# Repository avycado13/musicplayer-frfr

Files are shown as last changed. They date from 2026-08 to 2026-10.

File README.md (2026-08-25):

# Music Player

Schematic

I built a music player that's powered by a seeed studio xiao rp2350 devboard and a dfplayer mini.
My initial goal was to just build something, like literally anything, for Kai's speedrun huddle and i realized it would be cool to have a music player that i could take places without bringing my phone. I learnt alot about PCB design and i used this cool plugin called (KiCad Routing tools)[https://github.com/drandyhaas/KiCadRoutingTools] it sped up routing a lot because i just had to layout the parts and didnt have to painstakingly look through where each one goes.

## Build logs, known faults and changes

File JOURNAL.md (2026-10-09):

---
title: "My Music Player"
github: "avycado13/musicplayer-frfr"
description: "a basic music player i can use without pulling out my phone"
created_at: "2026-08-19"
---

# August 18: Started Project
I started this project for the lock in huddle and decided on using a seeed xiao rp2350 and a dfplayer mini for the main electronics. I also started working on the schematic and got half way through wiring the seeed,and the tp4056 chip with the battery.

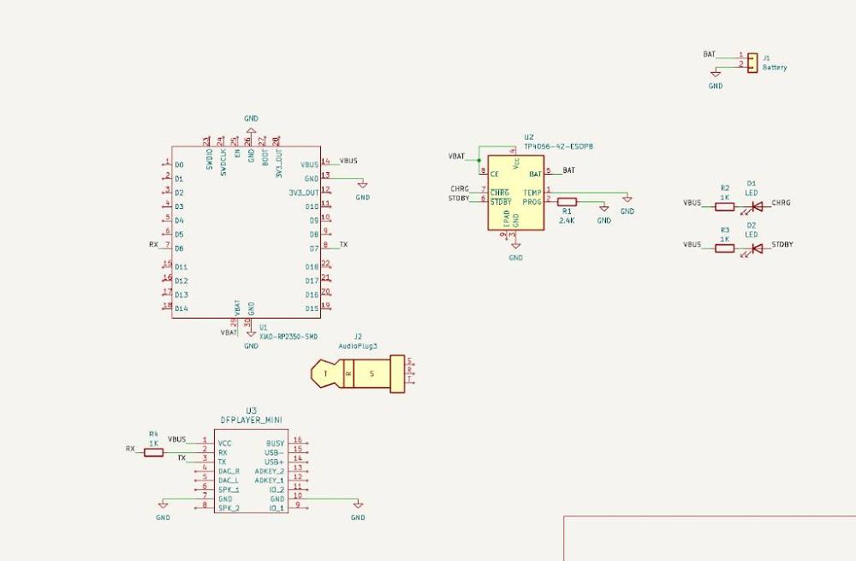
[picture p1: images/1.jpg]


**Total Time Spent: 2 Hours**

# August 19:
I locked in on finishing the schematic! I finished wiring the dfplayer mini with the audio jack and completed the battery circuitry! Kai Checked my schematic and realized i was send excess electricity from my leds to vbus not ground and i fixed it. When I was adding the oled, it turns out that theres basically no information about the display that i was going to use, which is also the same as the hackpad display.

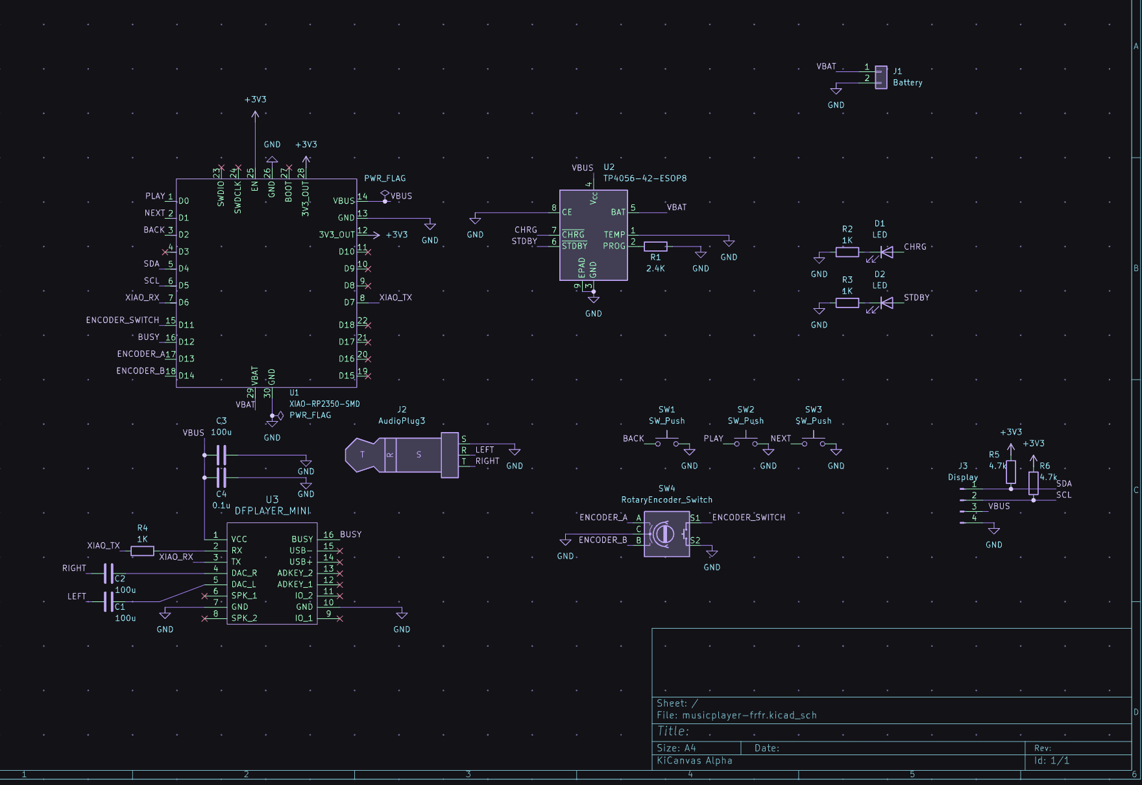
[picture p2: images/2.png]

**Total Time Spent: 2 Hours**
# August 19
Also finished my PCB and made it about the size of an ipod! I used this plugin called (KiCad Routing tools)[https://github.com/drandyhaas/KiCadRoutingTools] and it made routing so much easier and faster!

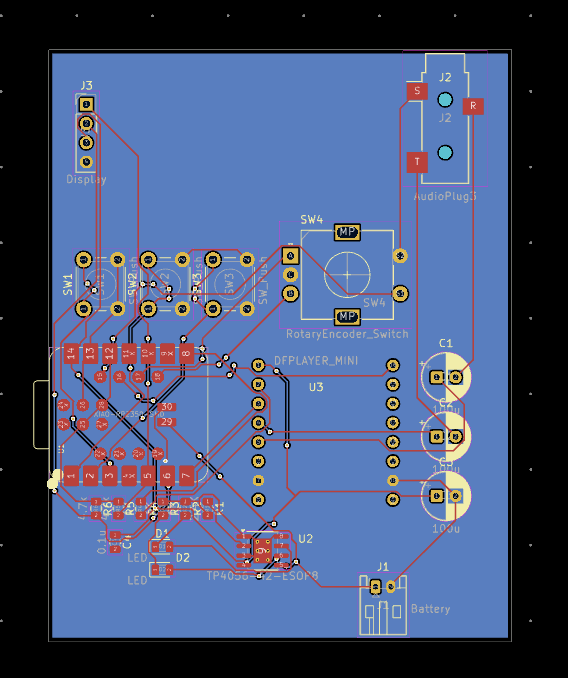
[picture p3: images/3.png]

**Total Time Spent: 1 Hour**

# August 21:
I made some changes to make the board a lot nicer like rounding the corners and redoing the layout so that the xiao is at the bottom. I also added a power switch so i should be able to toggle power and still charge it while off.

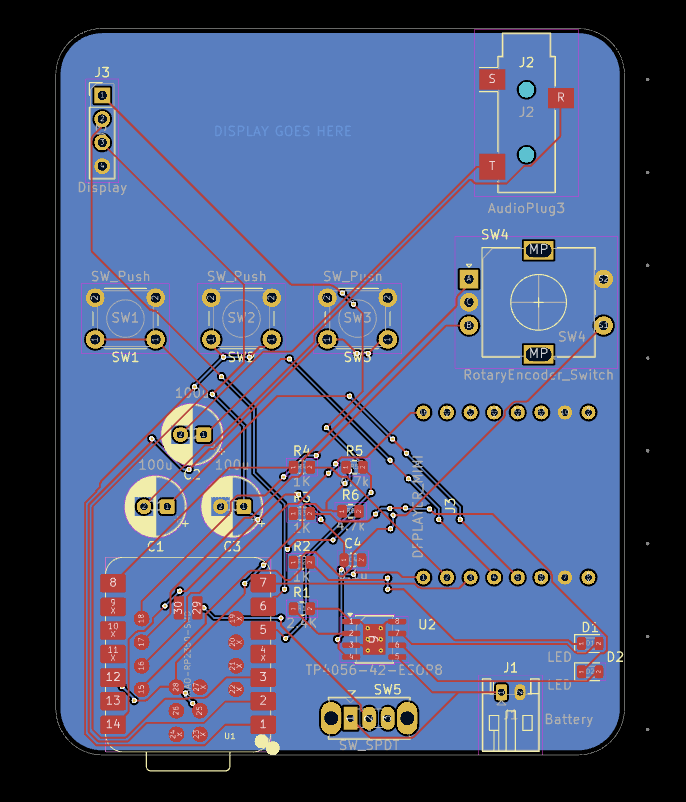
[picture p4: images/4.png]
updated PCB

**Total Time Spent: 1 Hour**

# August 24:
I fixed my fabrication files with this cool plugin called fabrication toolkit and I also fixed KiCad being stupid and not importing parts or something. I also added a nice silkscreen of orpheus going woah.

pcb with silkscreen
**Total Time Spent: 2 Hours**

# Sep 23: Redesigned Whole Schematic
I redesigned the whole schematic to be more interesting and be able to handle more use cases. I kept the Xiao RP2350 as a main processor for handling the UI and display, but removed the dedicated battery charging chip because I learnt that the Xiao supports that built in. I scrapped the DFplayer because it could only handle MP3 files, had weird ways of choosing what to play, and only supported mono audio. Instead, I replaced it with a PCM5102 DAC and a TPA6130A2RTJT Headphone amplifier. This gives me a lot better control over the volume and more flexibility over whats playing. The RP2350 does not have great support for decoding audio codecs like AAC, so I added an ESP32-S3-WROOM  connected to the RP2350 over SPI to do audio decoding and control the DAC and Amp. Another advantage of this is that the ESP32 also has Bluetooth and Wi-Fi so I could theoretically add support for a phone app to upload music and maybe even last.fm scrobbling support with an RTC. I switched it to use a 9 button array for controls and a bigger screen where you can actually read the text. For storing music, I used an SD Card reader that is directly connected over SDMMC to the ESP32.

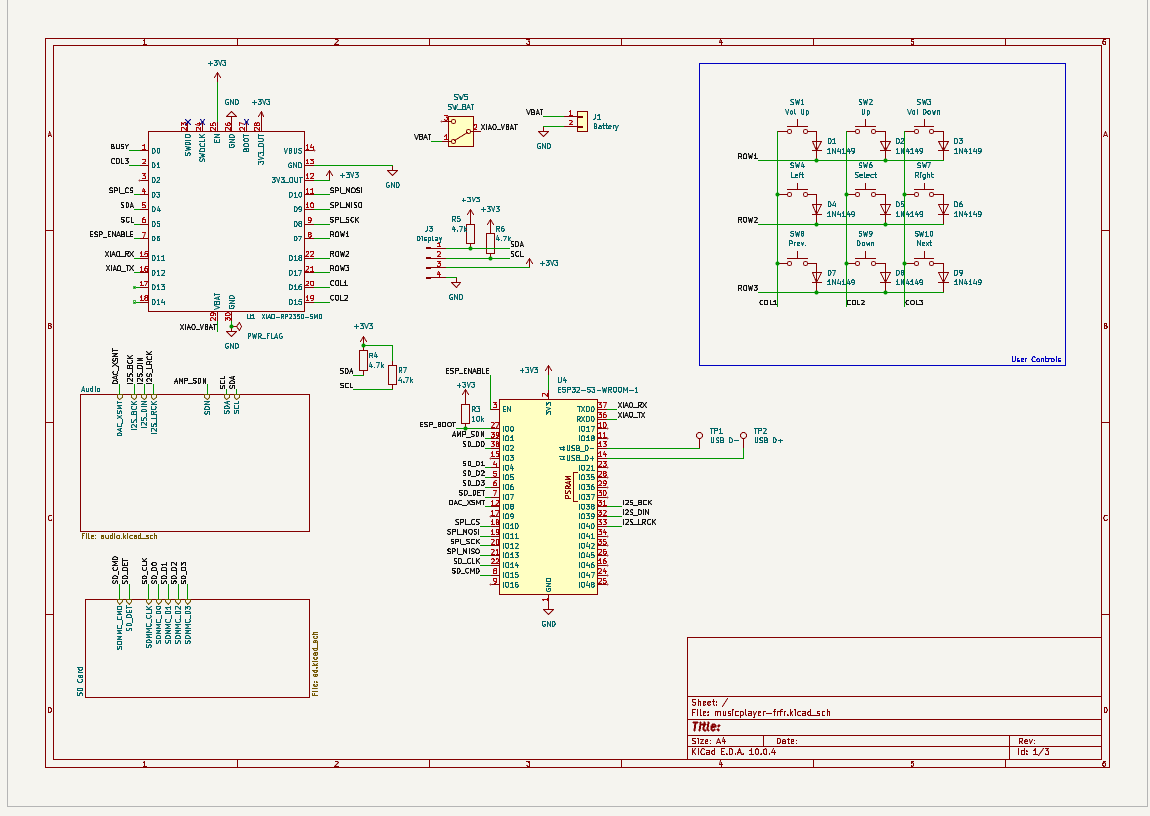
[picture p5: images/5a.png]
Main Sheet

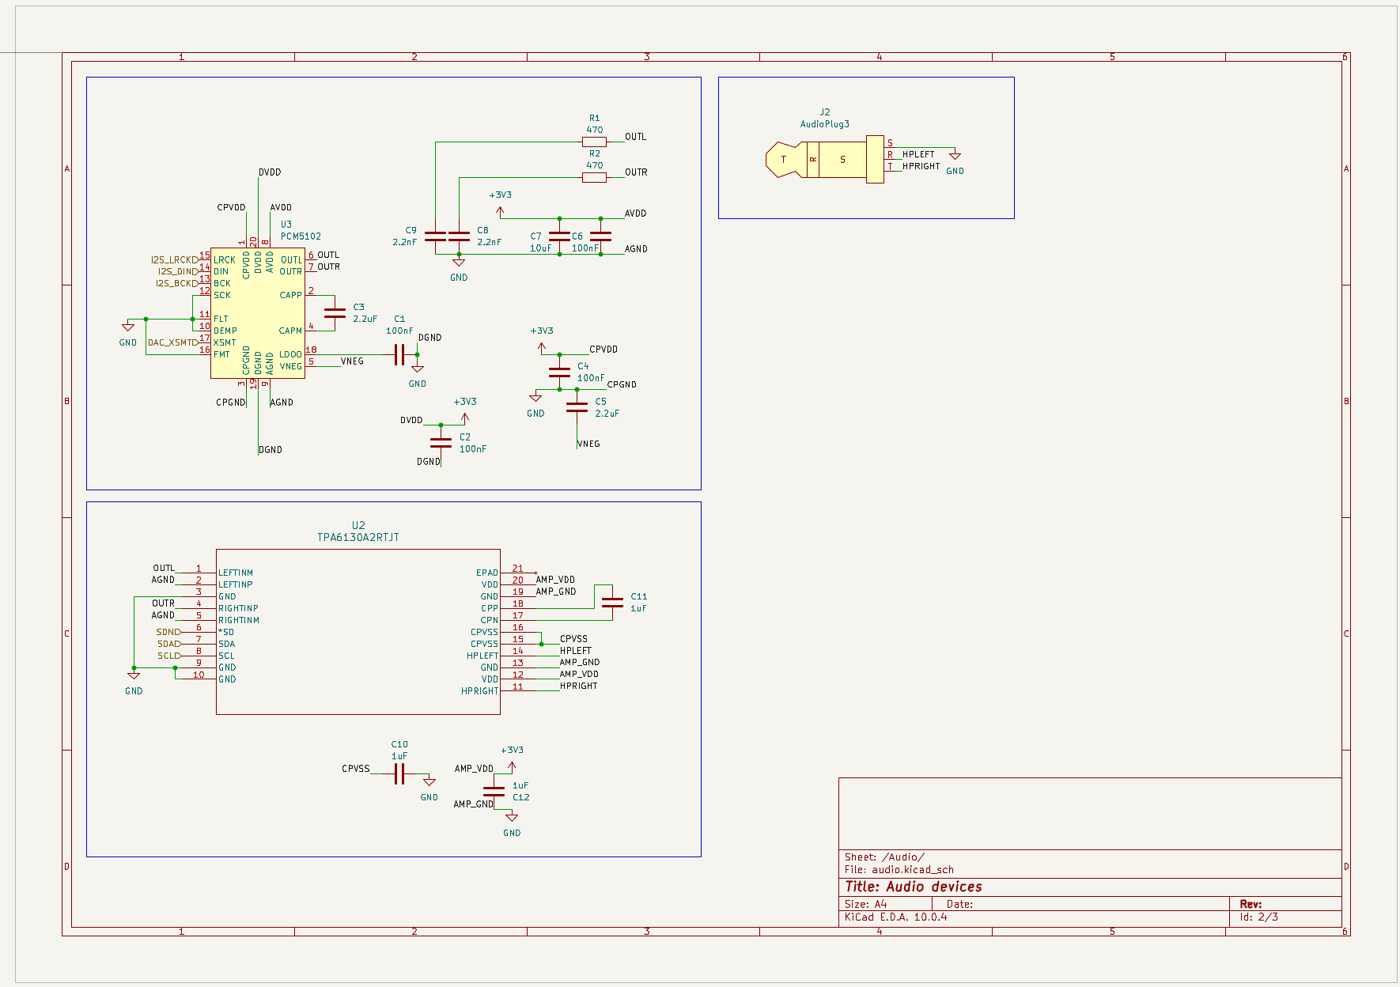
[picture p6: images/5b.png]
Audio Stuff

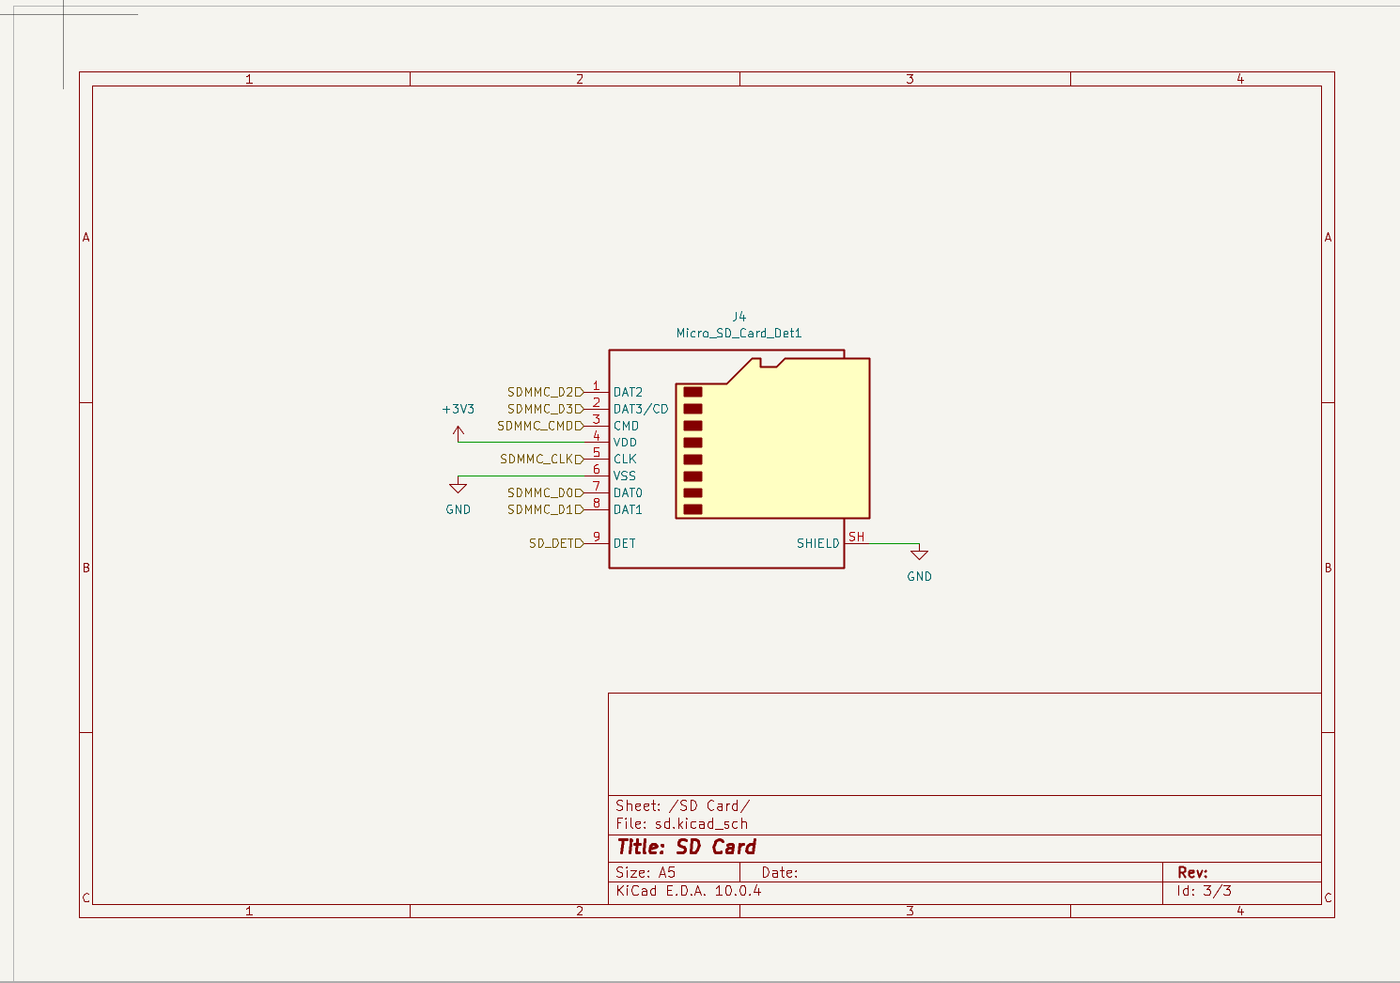
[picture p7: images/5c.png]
SD Card

**Total Time Spent: 3.5 Hours**

# Sep 28: Add RTC
I added a Real Time Clock to keep accurate time. Now I should hopefully be able to log when songs were played and scrobble them to Last.fm. I reorganized my schematic as well.

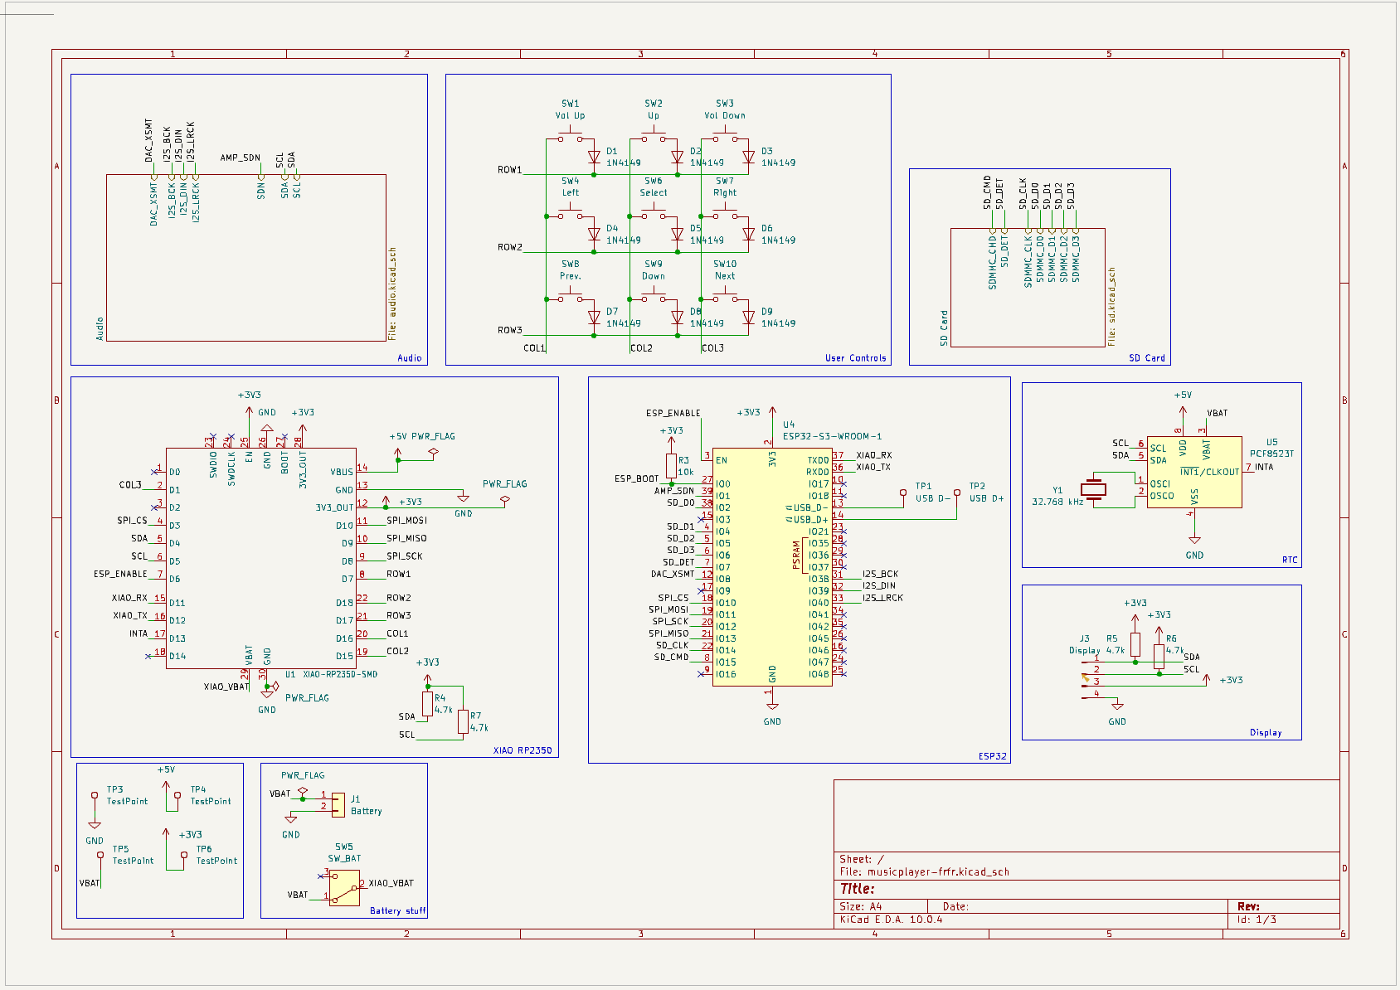
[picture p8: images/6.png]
Main Schematic

**Total Time Spent: 1.5 Hours**

# Oct 7: Assigned Footprints and Did Lay Out
I assigned all the footprints for the parts and did the layout. I had to be careful to avoid the ESP32's keep out zone and to make space for my display. I placed the headphone jack at the top for convenience when its in my pocket.
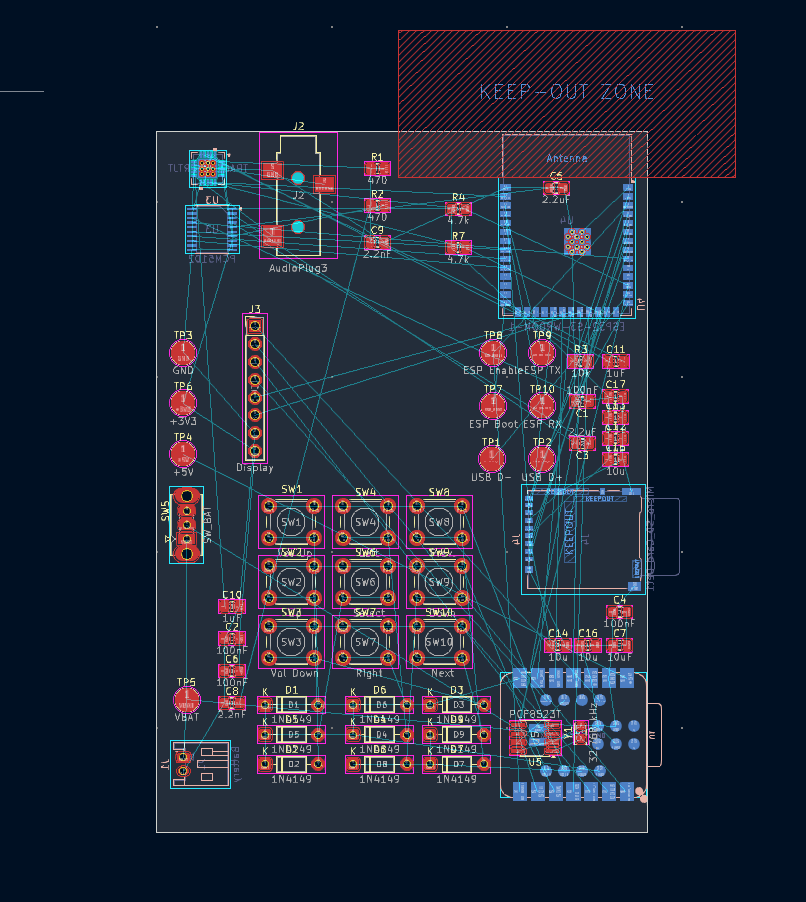
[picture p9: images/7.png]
PCB with Layout

**Total Time Spent: 3 Hours**

# Oct 9: Routed PCB
I routed the PCB and added a GND fill. I also cleaned up the schematic.
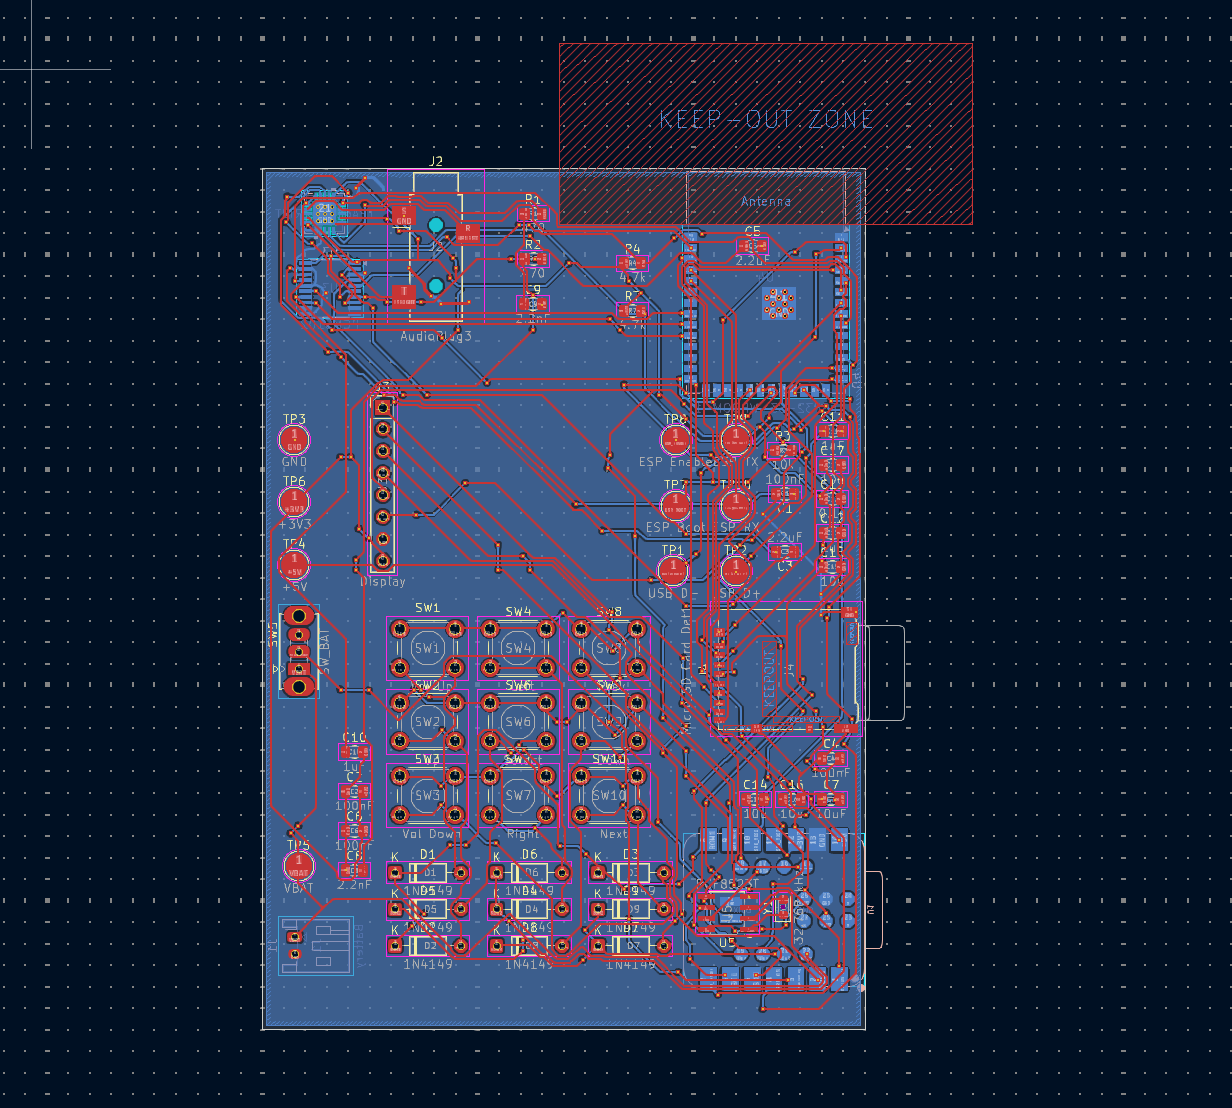
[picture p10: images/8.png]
Routed PCB

**Total Time Spent: 1 Hour**

# Oct 9: Generated Production Files
I generated my BOM and drill files from KiCad. I also made my IBOM for when I assemble it. All the KiCad dependencies should be embedded already.

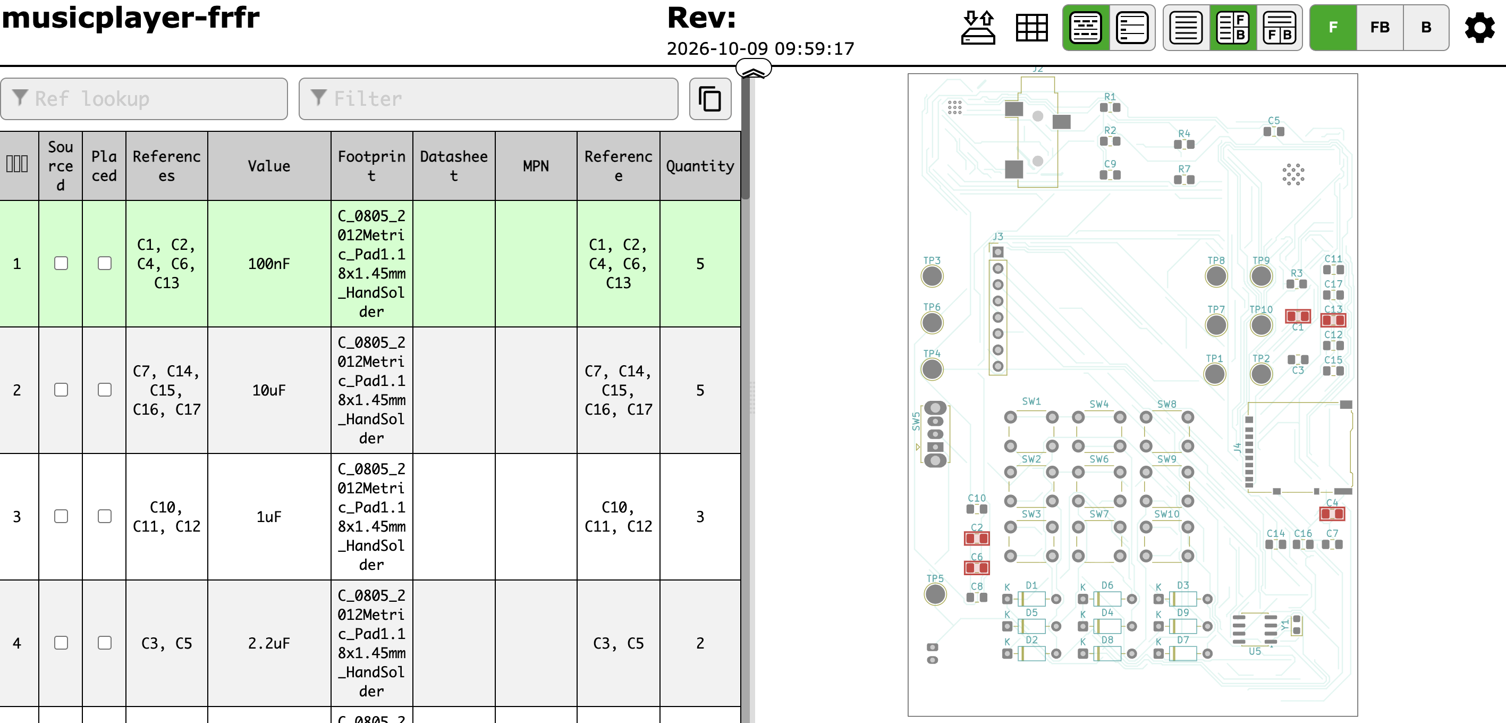
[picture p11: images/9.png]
IBOM

**Total Time Spent: 30 Minutes**

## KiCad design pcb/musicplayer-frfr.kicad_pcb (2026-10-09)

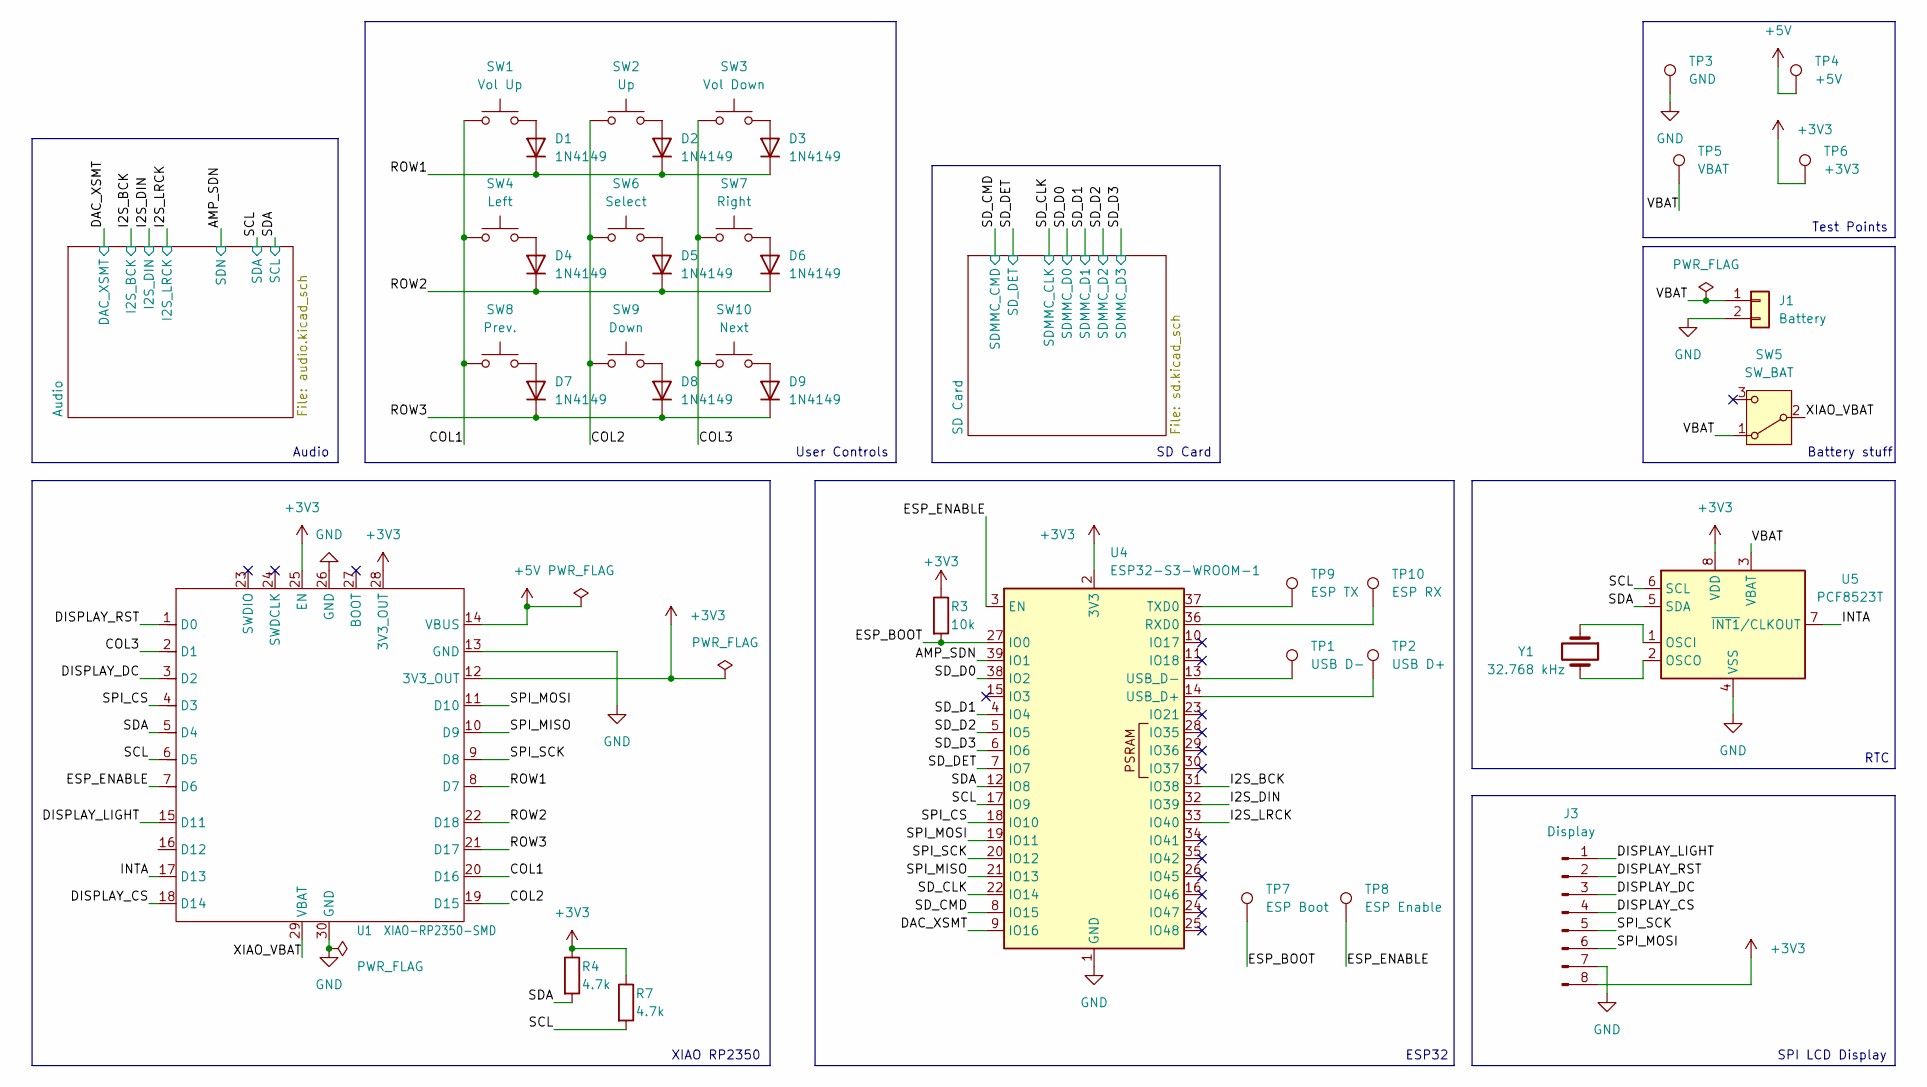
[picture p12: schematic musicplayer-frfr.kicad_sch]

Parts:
D1, D2, D3, D4, D5, D6, D7, D8, D9: 1N4149; D_DO-35_SOD27_P7.62mm_Horizontal
J1: Battery; JST_PH_S2B-PH-K_1x02_P2.00mm_Horizontal; MPN S2B-PH-K-S; LCSC PN C157932
J3: Display; PinHeader_1x08_P2.54mm_Vertical
R3: 10k; R_0805_2012Metric_Pad1.20x1.40mm_HandSolder
R4, R7: 4.7k; R_0805_2012Metric_Pad1.20x1.40mm_HandSolder
SW1: Vol Up; SW_PUSH_6mm; MPN TS4550CJ; LCSC PN C557612
SW2: Up; SW_PUSH_6mm; MPN TS4550CJ; LCSC PN C557612
SW3: Vol Down; SW_PUSH_6mm; MPN TS4550CJ; LCSC PN C557612
SW4: Left; SW_PUSH_6mm; MPN TS4550CJ; LCSC PN C557612
SW5: SW_BAT; SW_Slide_SPDT_Straight_CK_OS102011MS2Q; MPN OS102011MS2QN1; LCSC PN C221829
SW6: Select; SW_PUSH_6mm; MPN TS4550CJ; LCSC PN C557612
SW7: Right; SW_PUSH_6mm; MPN TS4550CJ; LCSC PN C557612
SW8: Prev.; SW_PUSH_6mm; MPN TS4550CJ; LCSC PN C557612
SW9: Down; SW_PUSH_6mm; MPN TS4550CJ; LCSC PN C557612
SW10: Next; SW_PUSH_6mm; MPN TS4550CJ; LCSC PN C557612
TP1: USB D-; TestPoint_Pad_D3.0mm
TP2: USB D+; TestPoint_Pad_D3.0mm
TP3: GND; TestPoint_Pad_D3.0mm
TP4: +5V; TestPoint_Pad_D3.0mm
TP5: VBAT; TestPoint_Pad_D3.0mm
TP6: +3V3; TestPoint_Pad_D3.0mm
TP7: ESP Boot; TestPoint_Pad_D3.0mm
TP8: ESP Enable; TestPoint_Pad_D3.0mm
TP9: ESP TX; TestPoint_Pad_D3.0mm
TP10: ESP RX; TestPoint_Pad_D3.0mm
U1: XIAO-RP2350-SMD; MPN 102010550; LCSC PN C41882923
U4: ESP32-S3-WROOM-1
U5: PCF8523T; SOIC-8_3.9x4.9mm_P1.27mm
Y1: 32.768 kHz; Crystal_SMD_2012-2Pin_2.0x1.2mm_HandSoldering

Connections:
+3V3: J3.8, R3.1, R4.1, R7.1, TP6.1 (1_1), U1.12 (3V3_OUT), U1.25 (EN), U1.28 (3V3_OUT), U4.2 (3V3), U5.8 (VDD); also elsewhere on the board
+5V: TP4.1 (1_1), U1.14 (VBUS)
/AMP_SDN: U4.39 (IO1); also elsewhere on the board
/COL1: SW1.1, SW4.1, SW8.1, U1.20 (D16)
/COL2: SW2.1, SW6.1, SW9.1, U1.19 (D15)
/COL3: SW3.1, SW7.1, SW10.1, U1.2 (D1)
/DAC_XSMT: U4.9 (IO16); also elsewhere on the board
/DISPLAY_CS: J3.4, U1.18 (D14)
/DISPLAY_DC: J3.3, U1.3 (D2)
/DISPLAY_LIGHT: J3.1, U1.15 (D11)
/DISPLAY_RST: J3.2, U1.1 (D0)
/ESP_BOOT: R3.2, TP7.1 (1_1), U4.27 (IO0)
/ESP_ENABLE: TP8.1 (1_1), U1.7 (D6), U4.3 (EN)
/I2S_BCK: U4.31 (IO38); also elsewhere on the board
/I2S_DIN: U4.32 (IO39); also elsewhere on the board
/I2S_LRCK: U4.33 (IO40); also elsewhere on the board
/INTA: U1.17 (D13), U5.7 (~INT1/CLKOUT)
/ROW1: D1.1 (K), D2.1 (K), D3.1 (K), U1.8 (D7)
/ROW2: D4.1 (K), D5.1 (K), D6.1 (K), U1.22 (D18)
/ROW3: D7.1 (K), D8.1 (K), D9.1 (K), U1.21 (D17)
/SCL: R7.2, U1.6 (D5), U4.17 (IO9), U5.6 (SCL); also elsewhere on the board
/SDA: R4.2, U1.5 (D4), U4.12 (IO8), U5.5 (SDA); also elsewhere on the board
/SD_CLK: U4.22 (IO14); also elsewhere on the board
/SD_CMD: U4.8 (IO15); also elsewhere on the board
/SD_D0: U4.38 (IO2); also elsewhere on the board
/SD_D1: U4.4 (IO4); also elsewhere on the board
/SD_D2: U4.5 (IO5); also elsewhere on the board
/SD_D3: U4.6 (IO6); also elsewhere on the board
/SD_DET: U4.7 (IO7); also elsewhere on the board
/SPI_CS: U1.4 (D3), U4.18 (IO10)
/SPI_MISO: U1.10 (D9), U4.21 (IO13)
/SPI_MOSI: J3.6, U1.11 (D10), U4.19 (IO11)
/SPI_SCK: J3.5, U1.9 (D8), U4.20 (IO12)
/VBAT: J1.1, SW5.1 (A), TP5.1 (1_1), U5.3 (VBAT)
/XIAO_VBAT: SW5.2 (B), U1.29 (VBAT)
GND: J1.2, J3.7, TP3.1 (1_1), U1.13 (GND), U1.26 (GND), U1.30 (GND), U4.1 (GND), U4.40 (GND), U4.41 (GND), U5.4 (VSS); also elsewhere on the board
unnamed: D1.2 (A), SW1.2
unnamed: D2.2 (A), SW2.2
unnamed: D3.2 (A), SW3.2
unnamed: D4.2 (A), SW4.2
unnamed: D5.2 (A), SW6.2
unnamed: D6.2 (A), SW7.2
unnamed: D7.2 (A), SW8.2
unnamed: D8.2 (A), SW9.2
unnamed: D9.2 (A), SW10.2
unnamed: TP10.1 (1_1), U4.36 (RXD0)
unnamed: TP9.1 (1_1), U4.37 (TXD0)
unnamed: TP2.1 (1_1), U4.14 (USB_D+)
unnamed: TP1.1 (1_1), U4.13 (USB_D-)
unnamed: U5.1 (OSCI), Y1.1
unnamed: U5.2 (OSCO), Y1.2

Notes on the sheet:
Audio
Battery stuff
XIAO RP2350
Test Points
SD Card
RTC
ESP32
User Controls
SPI LCD Display

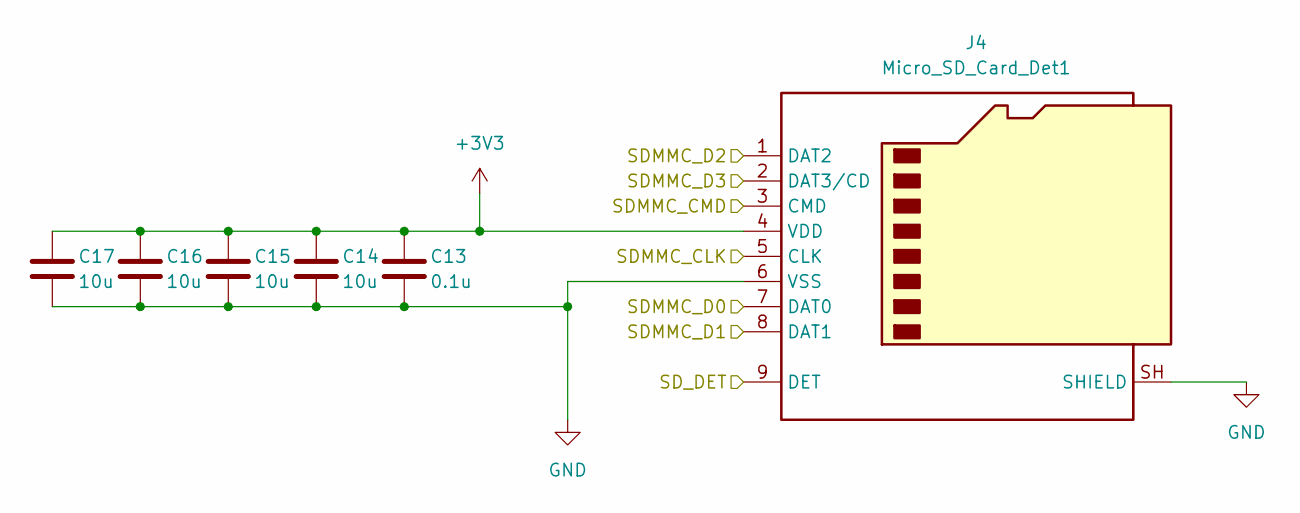
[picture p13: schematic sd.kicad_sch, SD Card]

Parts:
C13: 0.1u; C_0805_2012Metric_Pad1.18x1.45mm_HandSolder
C14, C15, C16, C17: 10u; C_0805_2012Metric_Pad1.18x1.45mm_HandSolder
J4: Micro_SD_Card_Det1; microSD_HC_Hirose_DM3AT-SF-PEJM5

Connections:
+3V3: C13.1, C14.1, C15.1, C16.1, C17.1, J4.4 (VDD); also elsewhere on the board
/SD_CLK: J4.5 (CLK); also elsewhere on the board
/SD_CMD: J4.3 (CMD); also elsewhere on the board
/SD_D0: J4.7 (DAT0); also elsewhere on the board
/SD_D1: J4.8 (DAT1); also elsewhere on the board
/SD_D2: J4.1 (DAT2); also elsewhere on the board
/SD_D3: J4.2 (DAT3/CD); also elsewhere on the board
/SD_DET: J4.9 (DET); also elsewhere on the board
GND: C13.2, C14.2, C15.2, C16.2, C17.2, J4.6 (VSS), J4.SH (SHIELD); also elsewhere on the board

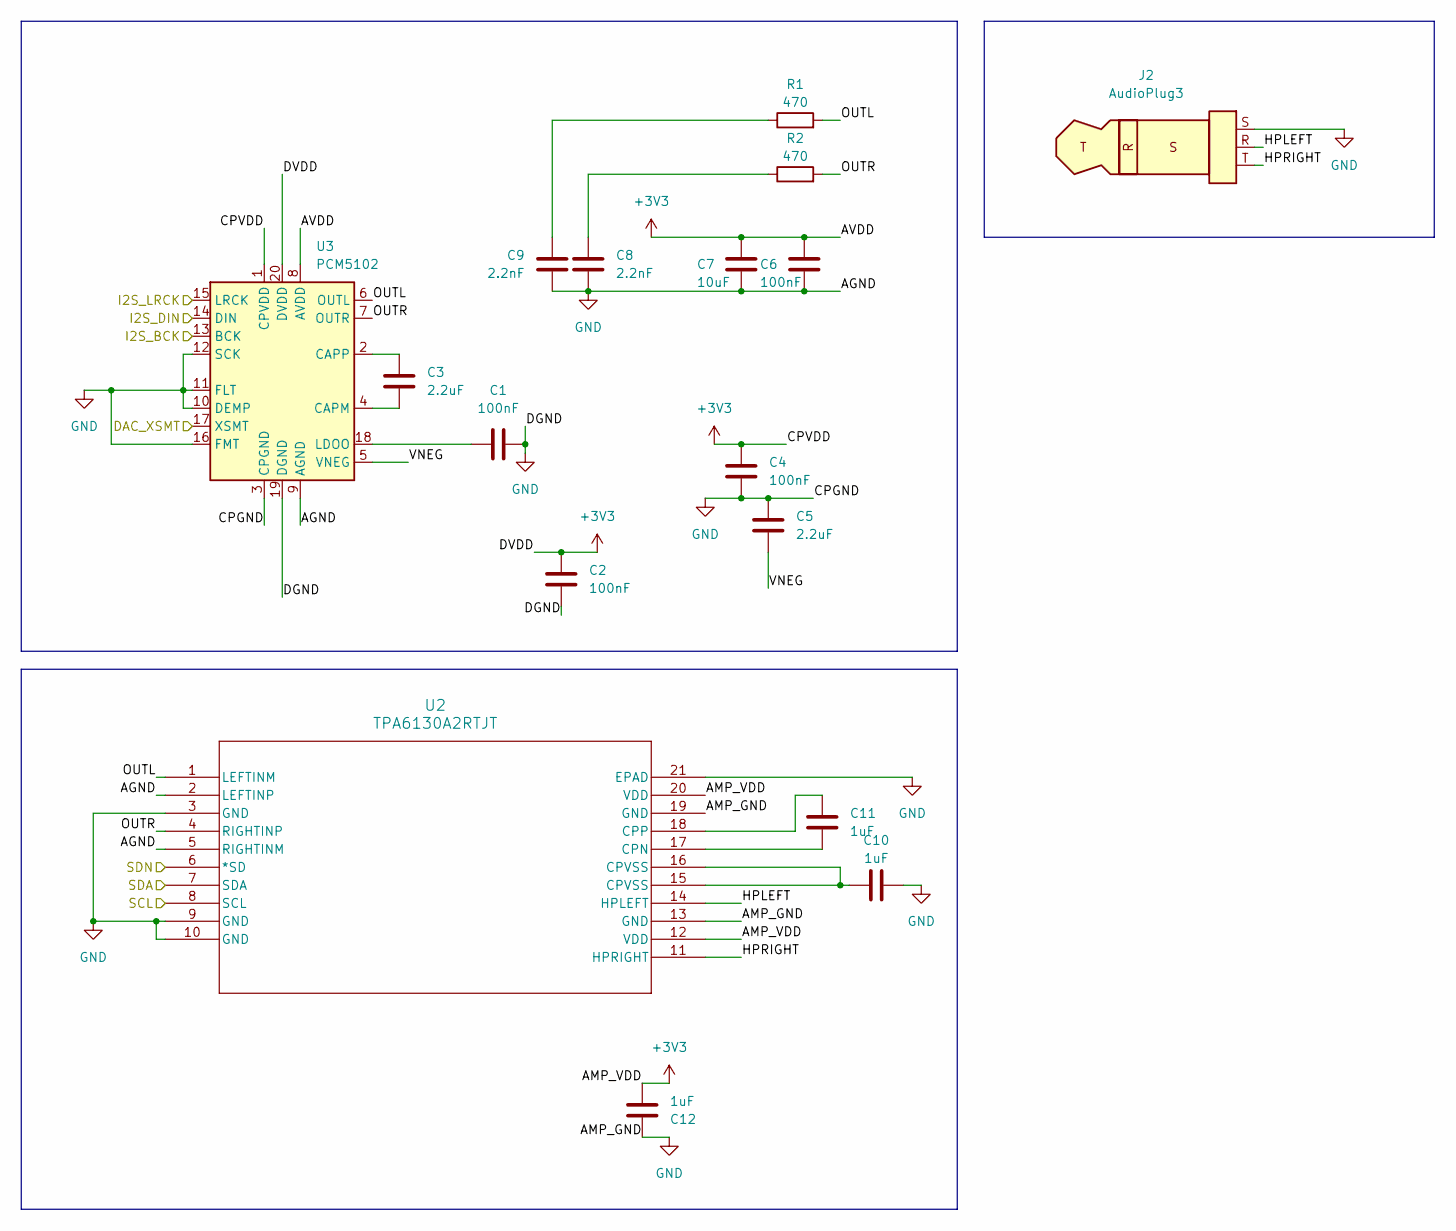
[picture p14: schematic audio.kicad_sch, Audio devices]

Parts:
C1, C2, C4, C6: 100nF; C_0805_2012Metric_Pad1.18x1.45mm_HandSolder
C3, C5: 2.2uF; C_0805_2012Metric_Pad1.18x1.45mm_HandSolder
C7: 10uF; C_0805_2012Metric_Pad1.18x1.45mm_HandSolder
C8, C9: 2.2nF; C_0805_2012Metric_Pad1.18x1.45mm_HandSolder
C10, C11, C12: 1uF; C_0805_2012Metric_Pad1.18x1.45mm_HandSolder
J2: AudioPlug3; Jack_3.5mm_CUI_SJ-3523-SMT_Horizontal; MPN SJ-3523-SMT-TR; LCSC PN C4991872
R1, R2: 470; R_0805_2012Metric_Pad1.20x1.40mm_HandSolder
U2: TPA6130A2RTJT; RTJ20_2P7X2P7
U3: PCM5102; TSSOP-20_4.4x6.5mm_P0.65mm

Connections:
+3V3: C2.2, C4.2, C6.2, C7.2, C12.1, U2.12 (VDD), U2.20 (VDD), U3.1 (CPVDD), U3.8 (AVDD), U3.20 (DVDD); also elsewhere on the board
/AMP_SDN: U2.6 (*SD); also elsewhere on the board
/Audio/HPLEFT: J2.R, U2.14 (HPLEFT)
/Audio/HPRIGHT: J2.T, U2.11 (HPRIGHT)
/Audio/OUTL: R1.2, U2.1 (LEFTINM), U3.6 (OUTL)
/Audio/OUTR: R2.2, U2.4 (RIGHTINP), U3.7 (OUTR)
/Audio/VNEG: C5.1, U3.5 (VNEG)
/DAC_XSMT: U3.17 (XSMT); also elsewhere on the board
/I2S_BCK: U3.13 (BCK); also elsewhere on the board
/I2S_DIN: U3.14 (DIN); also elsewhere on the board
/I2S_LRCK: U3.15 (LRCK); also elsewhere on the board
/SCL: U2.7 (SDA); also elsewhere on the board
/SDA: U2.8 (SCL); also elsewhere on the board
GND: C1.2, C2.1, C4.1, C5.2, C6.1, C7.1, C8.1, C9.2, C10.2, C12.2, J2.S, U2.2 (LEFTINP), U2.3 (GND), U2.5 (RIGHTINM), U2.9 (GND), U2.10 (GND), U2.13 (GND), U2.19 (GND), U2.21 (EPAD), U3.3 (CPGND), U3.9 (AGND), U3.10 (DEMP), U3.11 (FLT), U3.12 (SCK), U3.16 (FMT), U3.19 (DGND); also elsewhere on the board
unnamed: C8.2, R2.1
unnamed: C9.1, R1.1
unnamed: C10.1, U2.15 (CPVSS), U2.16 (CPVSS)
unnamed: C11.2, U2.17 (CPN)
unnamed: C11.1, U2.18 (CPP)
unnamed: C3.1, U3.4 (CAPM)
unnamed: C3.2, U3.2 (CAPP)
unnamed: C1.1, U3.18 (LDOO)

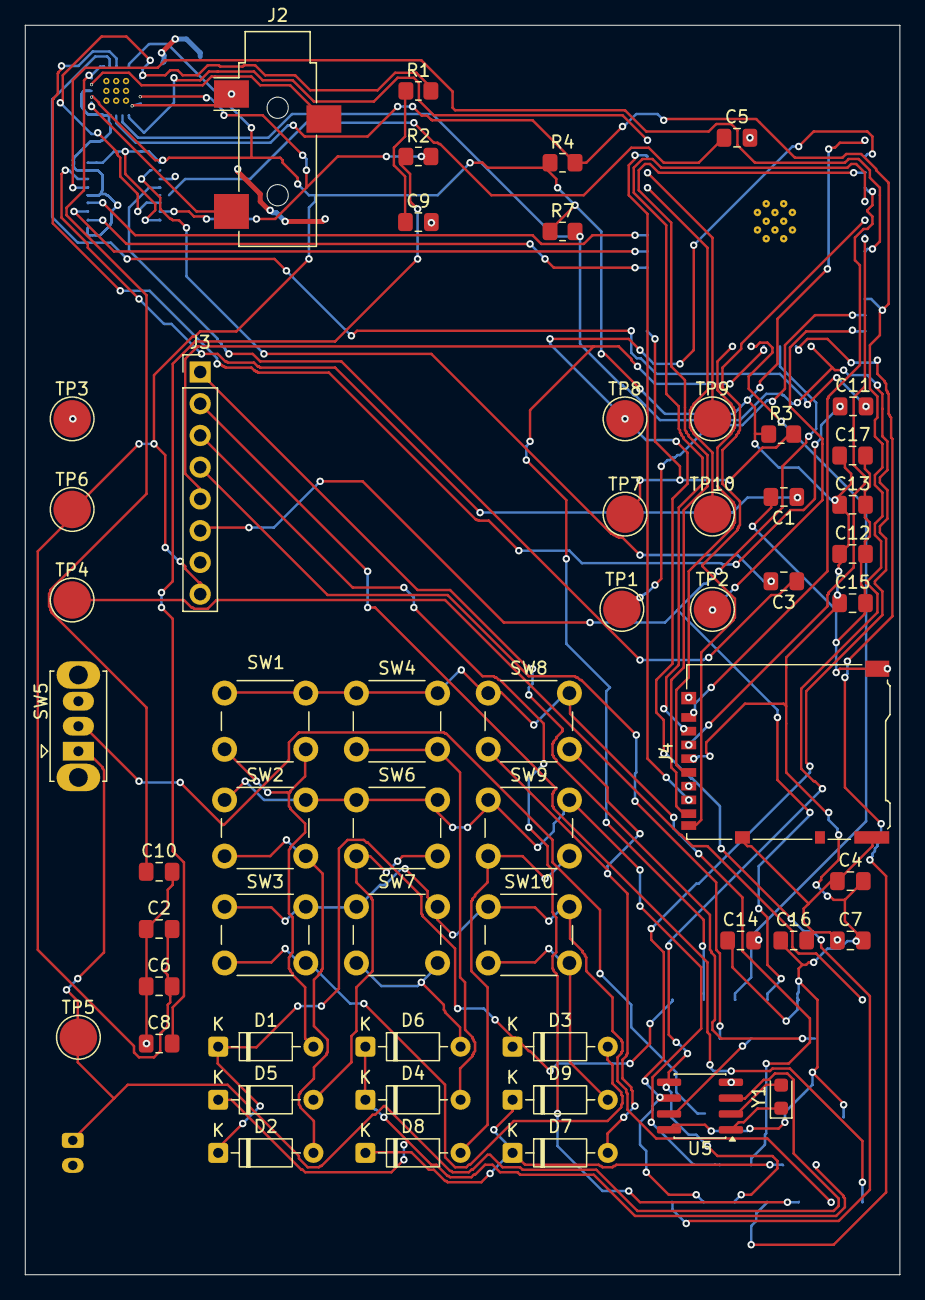
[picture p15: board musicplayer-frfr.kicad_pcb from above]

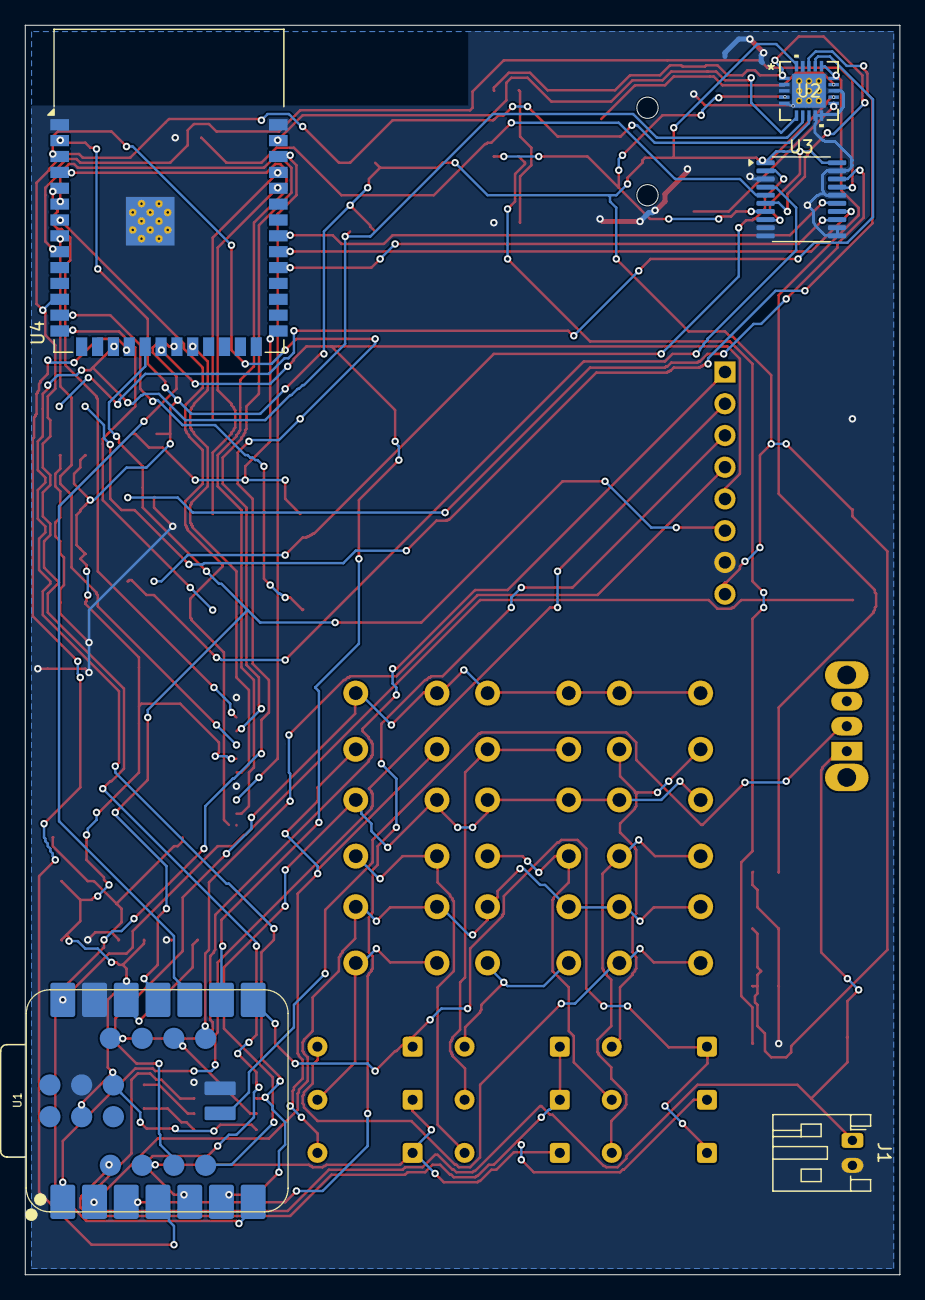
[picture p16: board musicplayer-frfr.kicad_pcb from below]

Board: 2 copper layers, 70.0 x 100.0 mm, 61 parts (5 on the bottom side), 64 nets.

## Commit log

2026-08-20 added some part numbers
    [musicplayer-frfr.kicad_sch]
2026-08-21 fix changes for shipping
    [musicplayer-frfr-B_Cu.gbr, musicplayer-frfr-B_Mask.gbr, musicplayer-frfr-B_Paste.gbr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]
2026-08-21 i screwed up the organization
2026-08-21 fix up pcb with cool new rounded corners and some layout changes. also added a power switch
    [musicplayer-frfr.kicad_pcb, musicplayer-frfr.kicad_sch]
2026-08-21 update journal
    [musicplayer-frfr-B_Cu.gbr, musicplayer-frfr-B_Mask.gbr, musicplayer-frfr-B_Paste.gbr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]
2026-08-25 fix up pcb bcuz kicad didnt place the right parts. also added fabrication files
    [musicplayer-frfr.kicad_pcb, musicplayer-frfr.kicad_sch]
2026-08-25 add silkscreen and hopefully prep for shipping
    [musicplayer-frfr.kicad_pcb]
2026-09-28 rework schemtaic to bet bigger badder and better
    [audio.kicad_sch, sd.kicad_sch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]
2026-09-29 add RTC and stuff
    [audio.kicad_sch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]
2026-10-07 fix JOURNAL.md hour formatting
    [sd.kicad_sch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]
2026-10-08 layout pcb
    [audio.kicad_sch, sd.kicad_sch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]
2026-10-09 clean up schematic
    [musicplayer-frfr.kicad_sch]
2026-10-09 route pcb
    [musicplayer-frfr.kicad_pcb]
2026-10-09 Generated PCB production files
    [musicplayer-frfr-B_Cu.gbr, musicplayer-frfr-B_Mask.gbr, musicplayer-frfr-B_Paste.gbr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]
2026-10-20 embed 3d models in pcb
2026-10-20 Journal cad time
